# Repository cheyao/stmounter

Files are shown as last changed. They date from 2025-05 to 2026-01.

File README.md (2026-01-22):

# Cool stm32 dev board

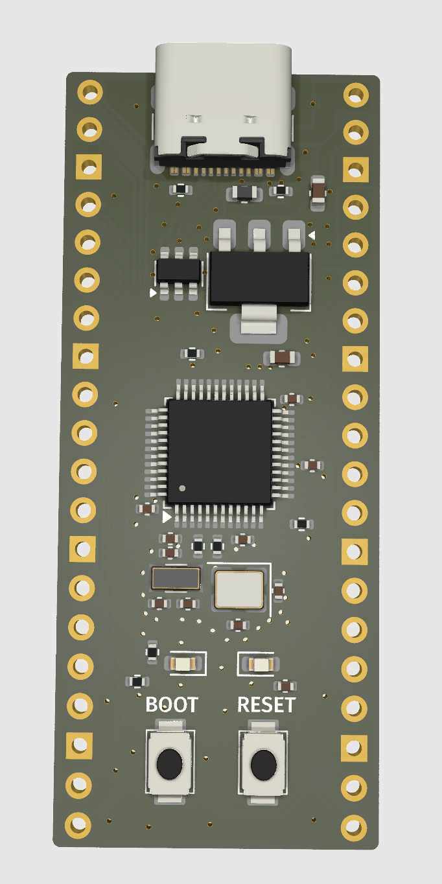
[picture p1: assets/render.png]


Get this cheap and small stm32 dev board! it's a drop in replacement for a raspberry pi pico, so upgrade your device's performance at no cost!

It even supports USB, has 2 on-board LEDs and has multiple ADC channels! How awesome :D

### Features

It has a STM32F373CCT on it, which has:
- 256KB flash
- 72MHz
- 32 Bit
- ARM® Cortex®-M4
- USB support

Paired with this processor this dev board is:
- In a raspberry pi pico foorprint - direct replacement
- Duan oscillators, accurate RTC timing
- USB C!
- 2 user LEDs
- dual layer design - low fabrication cost

### Why?

Why use a stm32 instead of a raspberry pi2040? The STM32 chips are more powerful, has more dedicated i/o pins and USB support!



As you can see, almost all signal traces are routed on a single layer, thus preserving the maximal amount of signal integrity. The ground plane is also not slices up, sllowing direct current return paths.

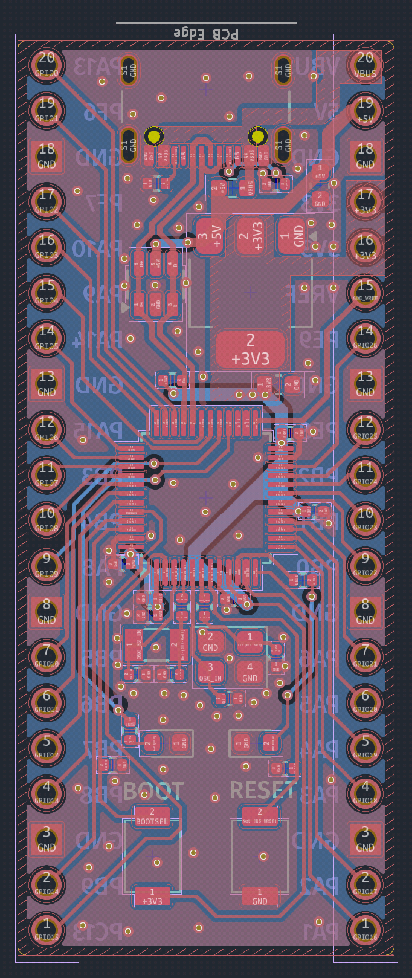
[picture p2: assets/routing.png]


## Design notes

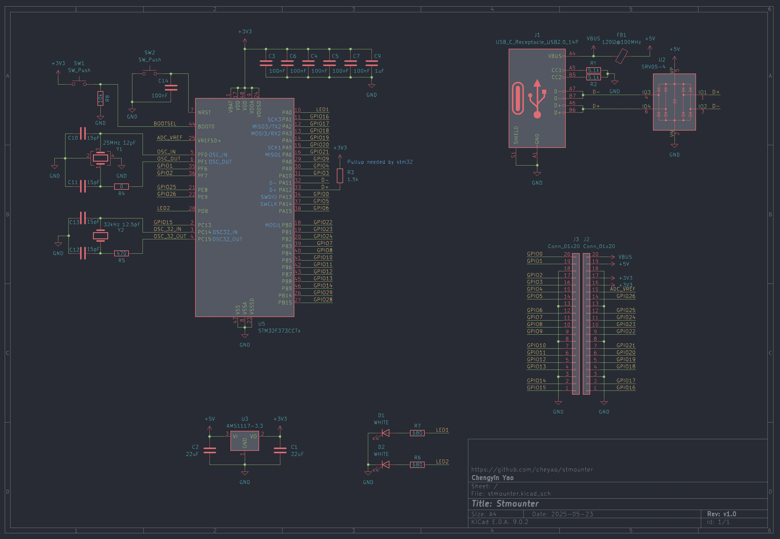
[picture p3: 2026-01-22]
assets/schemcatic.png

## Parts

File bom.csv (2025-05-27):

name | qty | price
pcb | 1 | 30$

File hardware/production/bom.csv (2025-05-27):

Designator | Footprint | Quantity | Value | LCSC Part #
C1, C2 | 0603 | 2 | 22uF | C59461
C10, C11, C12, C13 | 0402 | 4 | 15pF | C1548
C14, C3, C4, C5, C6, C7 | 0402 | 6 | 100nF | C1525
C9 | 0402 | 1 | 1uF | C52923
D1, D2 | 0603 | 2 | WHITE | C2290
FB1 | 0603 | 1 | 120Ω@100MHz | C14709
J1 | USB_C_Receptacle_GCT_USB4105-xx-A_16P_TopMnt_Horizontal | 1 | USB_C_Receptacle_USB2.0_14P | C2765186
R1, R2 | 0402 | 2 | 5.1k | C25905
R3 | 0402 | 1 | 1.5k | C25867
R4 | 0402 | 1 | 0 | C17168
R5 | 0402 | 1 | 470 | C25117
R6, R7 | 0402 | 2 | 680 | C25130
R8 | 0402 | 1 | 10k | C25744
SW1, SW2 | TS-1088-AR02016-Switch-SMD | 2 | SW_Push | C720477
U2 | SOT-23-6 | 1 | SRV05-4 | C7420376
U3 | SOT-223-3_TabPin2 | 1 | AMS1117-3.3 | C6186
U5 | LQFP-48_7x7mm_P0.5mm | 1 | STM32F373CCTx | C89403
Y1 | Crystal_SMD_3225-4Pin_3.2x2.5mm | 1 | 25MHz 12pF | C9006
Y2 | Crystal_SMD_3215-2Pin_3.2x1.5mm | 1 | 32kHz 12.5pF | C32346 (

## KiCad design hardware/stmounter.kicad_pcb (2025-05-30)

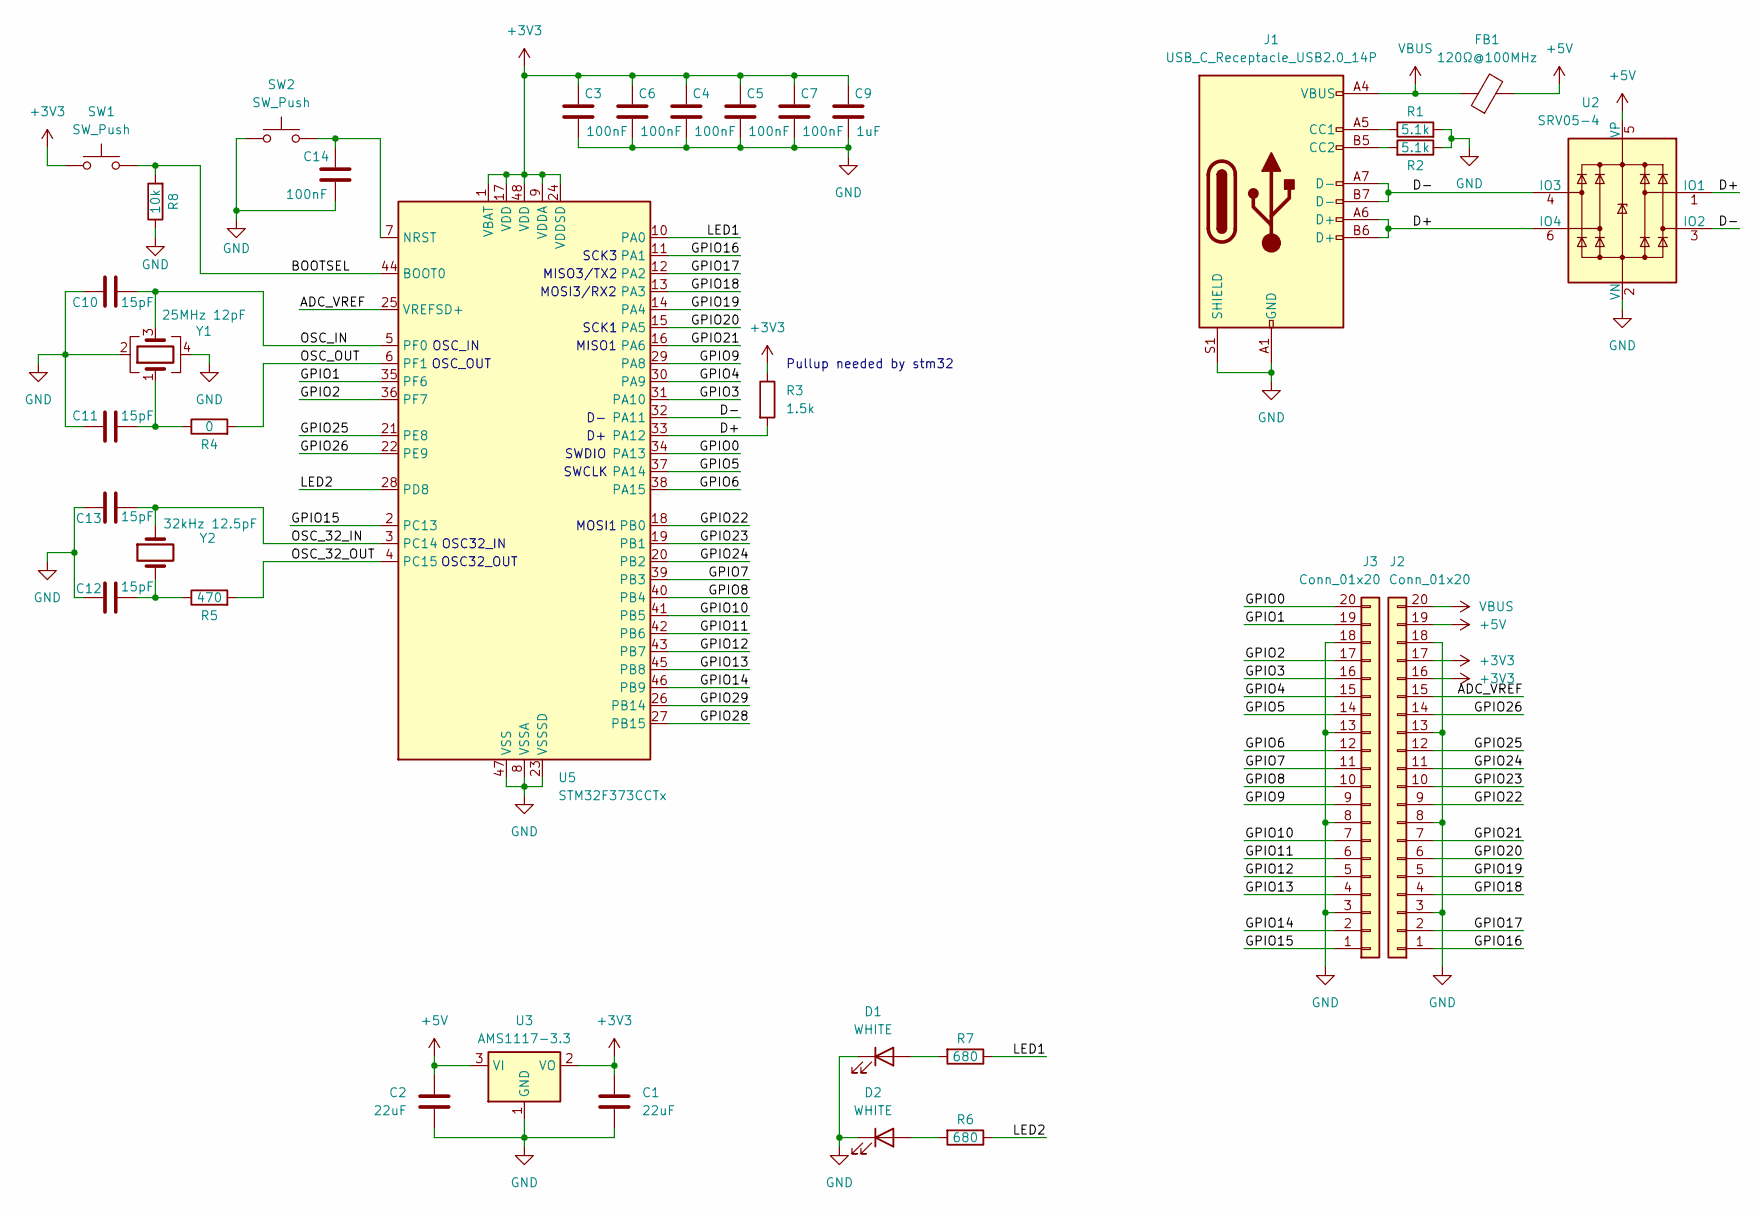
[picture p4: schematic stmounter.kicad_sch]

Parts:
C1, C2: 22uF; C_0603_1608Metric; LCSC Part # C59461
C3, C4, C5, C6, C7, C14: 100nF; C_0402_1005Metric; LCSC Part # C1525
C9: 1uF; C_0402_1005Metric; LCSC Part # C52923
C10, C11, C12, C13: 15pF; C_0402_1005Metric; LCSC Part # C1548
D1, D2: WHITE; LED_0603_1608Metric; LCSC Part # C2290
FB1: 120Ω@100MHz; L_0603_1608Metric; LCSC Part # C14709
J1: USB_C_Receptacle_USB2.0_14P; USB_C_Receptacle_GCT_USB4105-xx-A_16P_TopMnt_Horizontal; LCSC Part # C2765186
J2, J3: Conn_01x20; PinSocket_1x20_P2.54mm_Vertical
R1, R2: 5.1k; R_0402_1005Metric; LCSC Part # C25905
R3: 1.5k; R_0402_1005Metric; LCSC Part # C25867
R4: 0; R_0402_1005Metric; LCSC Part # C17168
R5: 470; R_0402_1005Metric; LCSC Part # C25117
R6, R7: 680; R_0402_1005Metric; LCSC Part # C25130
R8: 10k; R_0402_1005Metric; LCSC Part # C25744
SW1, SW2: SW_Push; TS-1088-AR02016-Switch-SMD; LCSC Part # C720477
U2: SRV05-4; SOT-23-6; LCSC Part # C7420376
U3: AMS1117-3.3; SOT-223-3_TabPin2; LCSC Part # C6186
U5: STM32F373CCTx; LQFP-48_7x7mm_P0.5mm; LCSC Part # C89403
Y1: 25MHz 12pF; Crystal_SMD_3225-4Pin_3.2x2.5mm; LCSC Part # C9006
Y2: 32kHz 12.5pF; Crystal_SMD_3215-2Pin_3.2x1.5mm; LCSC Part # C32346 (

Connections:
+3V3: C1.1, C3.1, C4.1, C5.1, C6.1, C7.1, C9.1, J2.16, J2.17, R3.1, SW1.1, U3.2 (VO), U5.1 (VBAT), U5.9 (VDDA), U5.17 (VDD), U5.24 (VDDSD), U5.48 (VDD)
+5V: C2.1, FB1.2, J2.19, U2.5 (VP), U3.3 (VI)
/ADC_VREF: J2.15, U5.25 (VREFSD+)
/BOOTSEL: R8.2, SW1.2, U5.44 (BOOT0)
/D+: J1.A6 (D+), J1.B6 (D+), R3.2, U2.1 (IO1), U2.6 (IO4), U5.33 (PA12)
/D-: J1.A7 (D-), J1.B7 (D-), U2.3 (IO2), U2.4 (IO3), U5.32 (PA11)
/GPIO0: J3.20, U5.34 (PA13)
/GPIO1: J3.19, U5.35 (PF6)
/GPIO2: J3.17, U5.36 (PF7)
/GPIO3: J3.16, U5.31 (PA10)
/GPIO4: J3.15, U5.30 (PA9)
/GPIO5: J3.14, U5.37 (PA14)
/GPIO6: J3.12, U5.38 (PA15)
/GPIO7: J3.11, U5.39 (PB3)
/GPIO8: J3.10, U5.40 (PB4)
/GPIO9: J3.9, U5.29 (PA8)
/GPIO10: J3.7, U5.41 (PB5)
/GPIO11: J3.6, U5.42 (PB6)
/GPIO12: J3.5, U5.43 (PB7)
/GPIO13: J3.4, U5.45 (PB8)
/GPIO14: J3.2, U5.46 (PB9)
/GPIO15: J3.1, U5.2 (PC13)
/GPIO16: J2.1, U5.11 (PA1)
/GPIO17: J2.2, U5.12 (PA2)
/GPIO18: J2.4, U5.13 (PA3)
/GPIO19: J2.5, U5.14 (PA4)
/GPIO20: J2.6, U5.15 (PA5)
/GPIO21: J2.7, U5.16 (PA6)
/GPIO22: J2.9, U5.18 (PB0)
/GPIO23: J2.10, U5.19 (PB1)
/GPIO24: J2.11, U5.20 (PB2)
/GPIO25: J2.12, U5.21 (PE8)
/GPIO26: J2.14, U5.22 (PE9)
/GPIO28: U5.27 (PB15)
/GPIO29: U5.26 (PB14)
/LED1: R7.1, U5.10 (PA0)
/LED2: R6.1, U5.28 (PD8)
/OSC_32_IN: C13.2, U5.3 (PC14), Y2.1
/OSC_32_OUT: R5.2, U5.4 (PC15)
/OSC_IN: C10.2, U5.5 (PF0), Y1.3
/OSC_OUT: R4.2, U5.6 (PF1)
GND: C1.2, C2.2, C3.2, C4.2, C5.2, C6.2, C7.2, C9.2, C10.1, C11.1, C12.1, C13.1, C14.2, D1.1 (K), D2.1 (K), J1.A1 (GND), J1.A12 (GND), J1.B1 (GND), J1.B12 (GND), J1.S1 (SHIELD), J2.3, J2.8, J2.13, J2.18, J3.3, J3.8, J3.13, J3.18, R1.2, R2.1, R8.1, SW2.1, U2.2 (VN), U3.1 (GND), U5.8 (VSSA), U5.23 (VSSSD), U5.47 (VSS), Y1.2, Y1.4
unnamed: C11.2, R4.1, Y1.1
unnamed: C12.2, R5.1, Y2.2
unnamed: D1.2 (A), R7.2
unnamed: D2.2 (A), R6.2
unnamed: J1.A5 (CC1), R1.1
unnamed: J1.B5 (CC2), R2.2
unnamed: C14.1, SW2.2, U5.7 (NRST)
VBUS: FB1.1, J1.A4 (VBUS), J1.A9 (VBUS), J1.B4 (VBUS), J1.B9 (VBUS), J2.20

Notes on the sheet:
OSC_IN
MISO1
SWCLK
MOSI1
Pullup needed by stm32
OSC32_IN
SWDIO
SCK1
SCK3
OSC32_OUT
OSC_OUT
MISO3/TX2
MOSI3/RX2

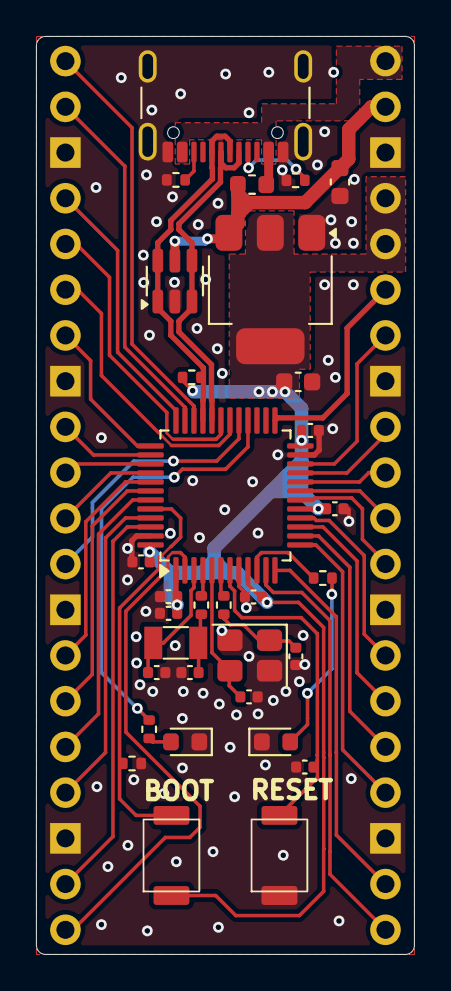
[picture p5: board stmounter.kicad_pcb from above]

Board: 2 copper layers, 21.0 x 51.0 mm, 34 parts (0 on the bottom side), 48 nets.

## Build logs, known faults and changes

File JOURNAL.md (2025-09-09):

---
title: "Stmounter"
author: "Chengyin Yao"
description: "STM32 Development Board"
created_at: "2025-05-23"
---

# Stmounter

- Total time spent: 14.5h

Damn I can't think of a better name >.<

-------------------

## 23/05

But I've started the schematic! Progress looking quite good right now. The stm32 looks like an easy chip.



- Time spent: 1h

-------------------

## 24/05

I've researched a toooon about the usb c shield connection: resistor cap pair, ferrite bear, no conenction, connect directly etc. Figured that the best way to connect it is directly to a gnd pour.

Also started designing the schematic!



- 2h

-------------------

Decided on a raspi pico form factor because why not ;p It'll be a drop-in replacement.



- 1.5h

-------------------

Finally found a stm32 [getting started manual](https://www.st.com/resource/en/application_note/cd00164185-getting-started-with-stm32f10xxx-hardware-development-stmicroelectronics.pdf)! This will make my like easier ;p

Only 29 pages tho, how little.

- 2h

-------------------

Okay I've opened like 4 pdfs now, in datasheet hell... Welp this is easier then my fpga though. Calculating oscillator capacitance rn.

I've calculated the capacitance and continued routing:



- 1.5h

-------------------

## 25/05

Okay I've finished routing the v1 of the board!



Buuuut I think I messed up the chip selection... I need a 2.5$ chip for the USB programming option :(

Time for v2

- 2.5h

-------------------

Started drawing the schematic for the STM32F373CCT, also reorganized the top part of the PCB.



- 1h

-------------------

Okay I spent the whole afternoon on this, finished rev 2!!!



- 2.5h

-------------------

Updated readme... Ugh

- 0.5h

-------------------

Aaaand some more

- 0.5h

--------------------------

# 09/01

Got my boards, and finally got time to ship them!



The usage is pretty simple: Plug in a usb c cable and just press the boot & reset button, and program the stm32 chips as you would normally!

Happy hacking :)
